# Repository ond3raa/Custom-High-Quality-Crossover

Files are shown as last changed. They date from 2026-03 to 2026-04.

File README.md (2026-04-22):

# Description
This is an audio crossover. Its function is to take an audio signal and split it into multiple speakers based on specific frequencies. It is used in speaker cabinets and sound systems to achieve the correct sound.
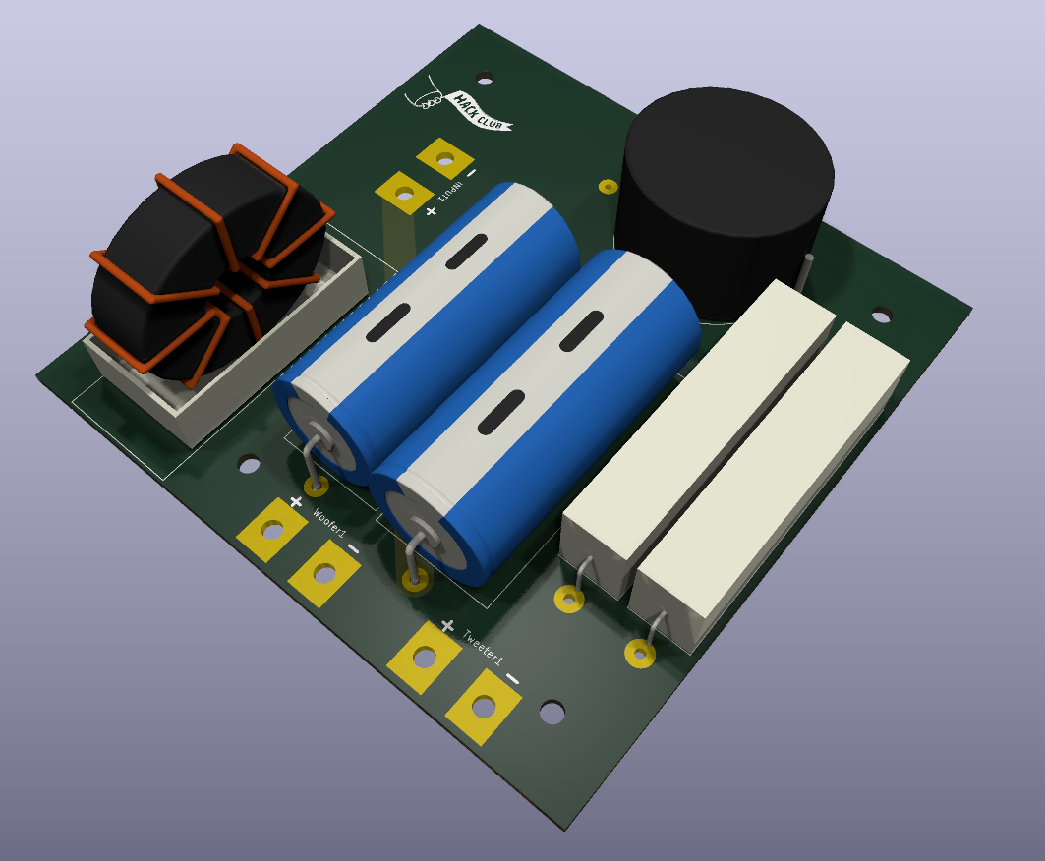
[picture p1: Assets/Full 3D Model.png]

# How to use
The usage is quite simple: just assemble the PCB, solder the cables from the amplifier to the input, and connect the mid-bass speaker to the "woofer" output and the tweeter to the "tweeter" output.

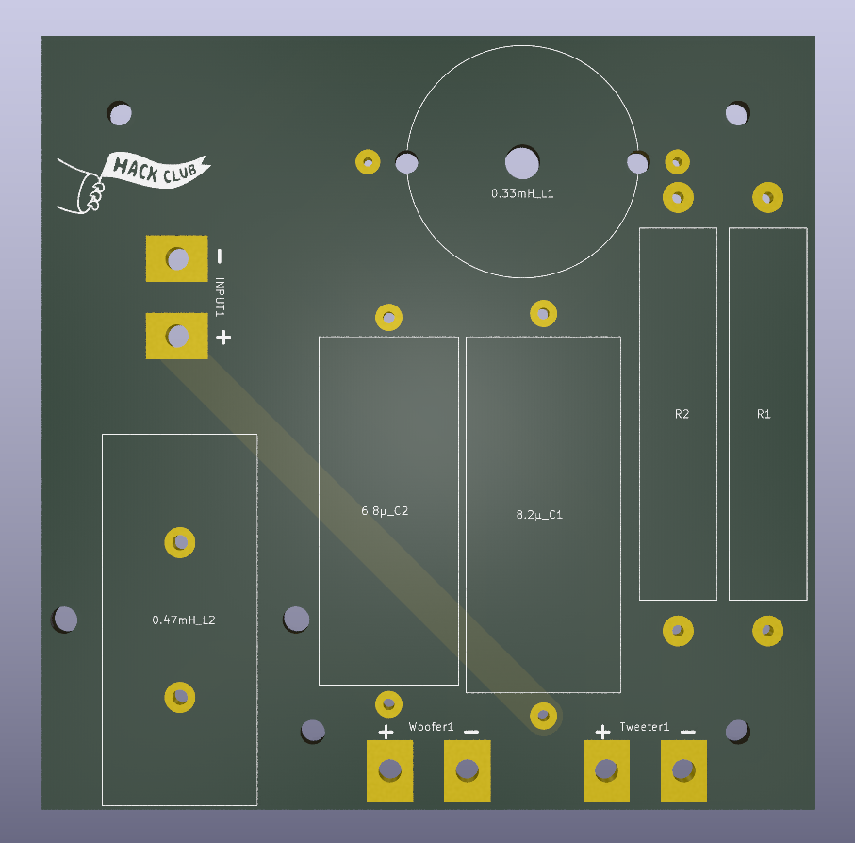
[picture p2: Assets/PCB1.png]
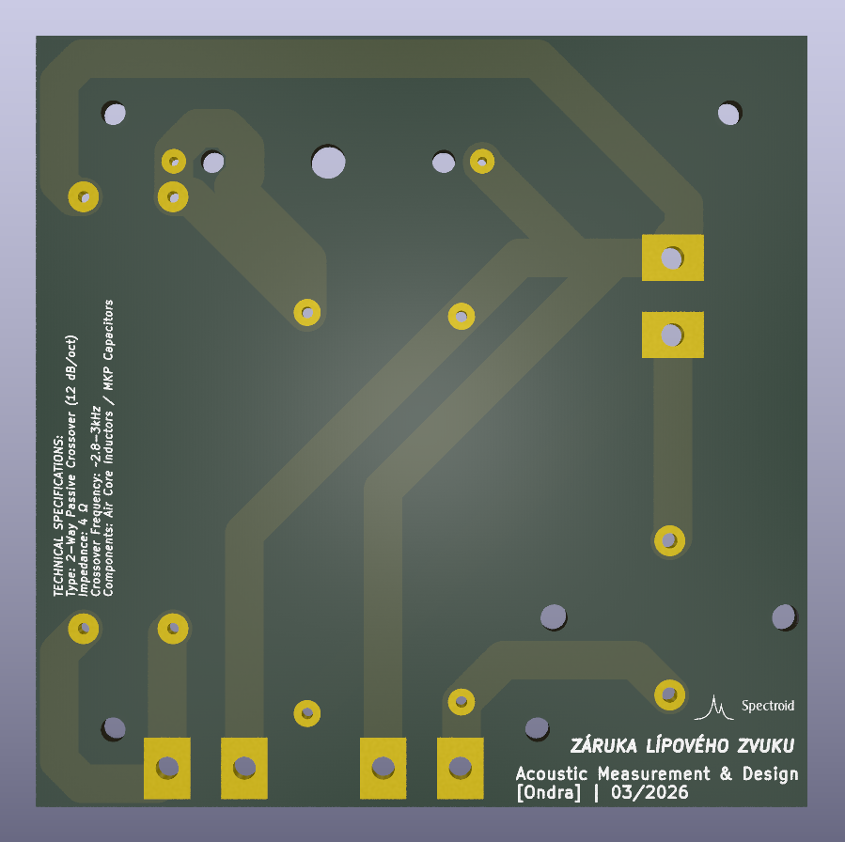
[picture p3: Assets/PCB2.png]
 

# Why I made this
I created this project because I built speaker cabinets using car speakers and wired them the same way they were in the car. At frequencies around 2-10kHz, both speakers played simultaneously due to the missing 2nd-
order crossover, and the sound was sharp and aggressive. I designed this 2nd-order crossover to audibly eliminate this problem and improve the overall sound quality.

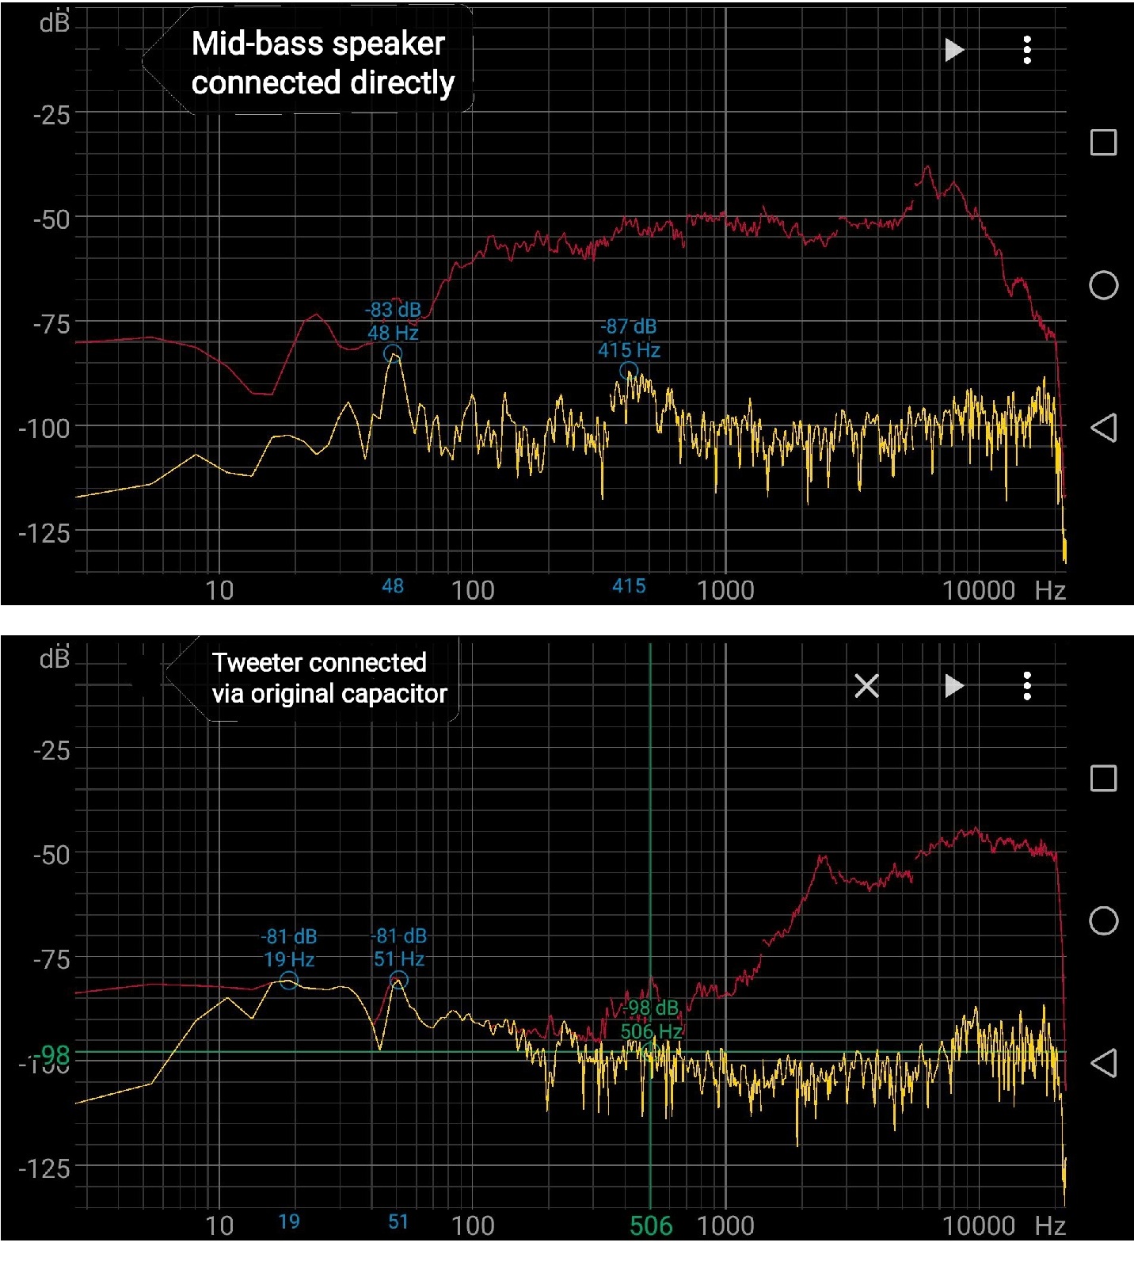
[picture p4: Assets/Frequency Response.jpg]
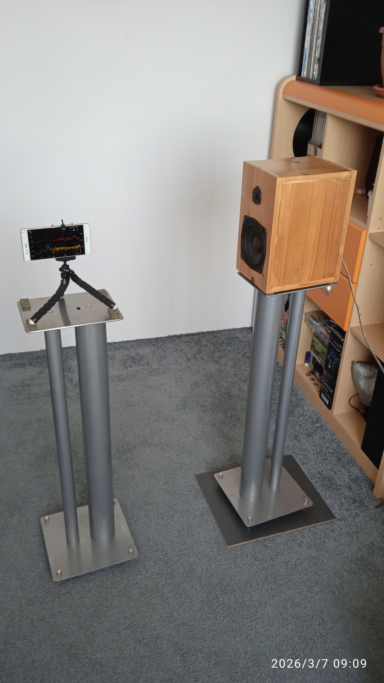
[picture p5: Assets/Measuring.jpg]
 

# Firmware & Software
This project is a passive analog audio crossover. It uses only discrete components, including capacitors, inductors, and resistors for frequency filtering. There are no microcontrollers or integrated circuits involved, so no firmware is required for this project to operate.
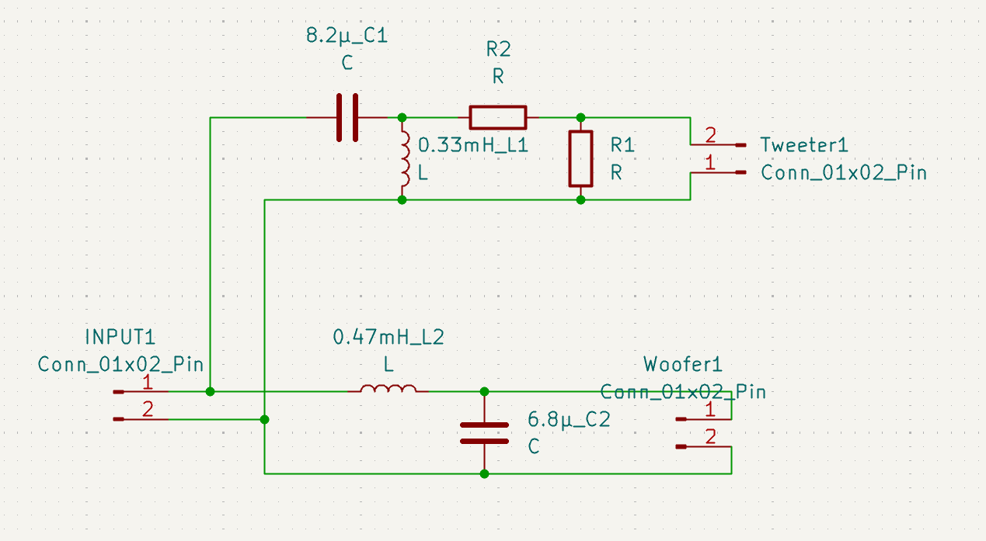
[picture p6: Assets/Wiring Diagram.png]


### BOM

| Part | Value | Quantity | Price (CZK) | Link |
| :--- | :--- | :--- | :--- | :--- |
| Connecting cables | | 6 | 0 - I have them | - |
| Mounting screws | M3 | 8 | 0 - I have them | - |
| Air coil L1 | 0.33mH | 2 | 260 | [Link](https://www.reproobchod.cz/dexon-vzduchova-civka-0-33mh-0-8mm/) |
| Air coil L2 | 0.47mH | 2 | 338 | [Link](https://www.reproobchod.cz/monacor-lsip-47-2-vzduchova-civka-0-47mh-0-85mm/) |
| Capacitor C1 | 8.2uF | 2 | 192 | [Link](https://www.reproobchod.cz/kondenzator-monacor-mkpa-82-8-2uf-250v-dc-mkp/) |
| Capacitor C2 | 6.8uF | 2 | 190 | [Link](https://www.reproobchod.cz/kondenzator-monacor-mkpa-68-6-8uf-250v-dc-mkp/) |
| Resistor R1 | 1 Ohm | 2 | 60 | [Link](https://www.reproobchod.cz/rezistor-keramicky-visaton-r-1ohm-10-w/) |
| Resistor R2 | 1.5 Ohm | 2 | 60 | [Link](https://www.reproobchod.cz/rezistor-keramicky-visaton-r-1-5ohm-10-w/) |
| Resistor R3 | 2.2 Ohm | 2 | 36 | [Link](https://www.reproobchod.cz/rezistor-keramicky-dratovy-tesla-tr271-2r2-10w/) |
| Resistor R4 | 3 Ohm | 2 | 36 | [Link](https://www.reproobchod.cz/rezistor-keramicky-dratovy-tesla-tr271-3r0-10w/) |
| Shipping | reproobchod.cz | 1 | 69 | - |
| PCB | JLCPCB | 2 | ~90 | [Link](https://jlcpcb.com/) |
| **Total to pay** | | | **1331 CZK** | **~$63.97 USD** |

## Note:
## The real value in dollars is here in the BOM. It is also in the blueprint project, but it differs due to different exchange rates
The 3D component models used in the CAD assembly and STEP file are **representative placeholders**.

I selected these models based on their physical dimensions (length and width) to verify component clearance and PCB seating. The actual high-quality audio components (inductors and capacitors) used for assembly are precisely specified in the **Bill of Materials**.

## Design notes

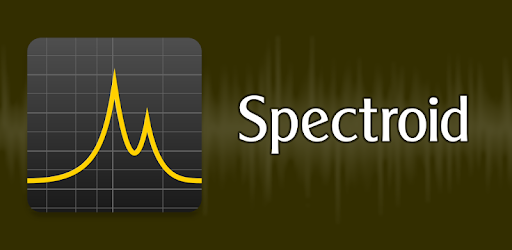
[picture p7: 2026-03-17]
3D model/Used models/org.intoorbit.spectrum-header.png

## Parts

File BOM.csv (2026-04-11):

Designator | Value | Quantity | Link
Connecting cables |  | 6 but i have them
Mounting screws | M3 | 8 but i have them
L1 | 0.33mH | 2 | https://www.reproobchod.cz/dexon-vzduchova-civka-0-33mh-0-8mm/
L2 | 0.47mH | 2 | https://www.reproobchod.cz/monacor-lsip-47-2-vzduchova-civka-0-47mh-0-85mm/
C1 | 8.2uF | 2 | https://www.reproobchod.cz/kondenzator-monacor-mkpa-82-8-2uf-250v-dc-mkp/
C2 | 6.8uF | 2 | https://www.reproobchod.cz/kondenzator-monacor-mkpa-68-6-8uf-250v-dc-mkp/
R1 | 1 Ohm | 2 | https://www.reproobchod.cz/rezistor-keramicky-visaton-r-1ohm-10-w/
R2 | 1.5 Ohm | 2 | https://www.reproobchod.cz/rezistor-keramicky-visaton-r-1-5ohm-10-w/
R3 | 2.2 Ohm | 2 | https://www.reproobchod.cz/rezistor-keramicky-dratovy-tesla-tr271-2r2-10w/
R4 | 3 Ohm | 2 | https://www.reproobchod.cz/rezistor-keramicky-dratovy-tesla-tr271-3r0-10w/
JLCPCB | Custom | 2 | https://jlcpcb.com/

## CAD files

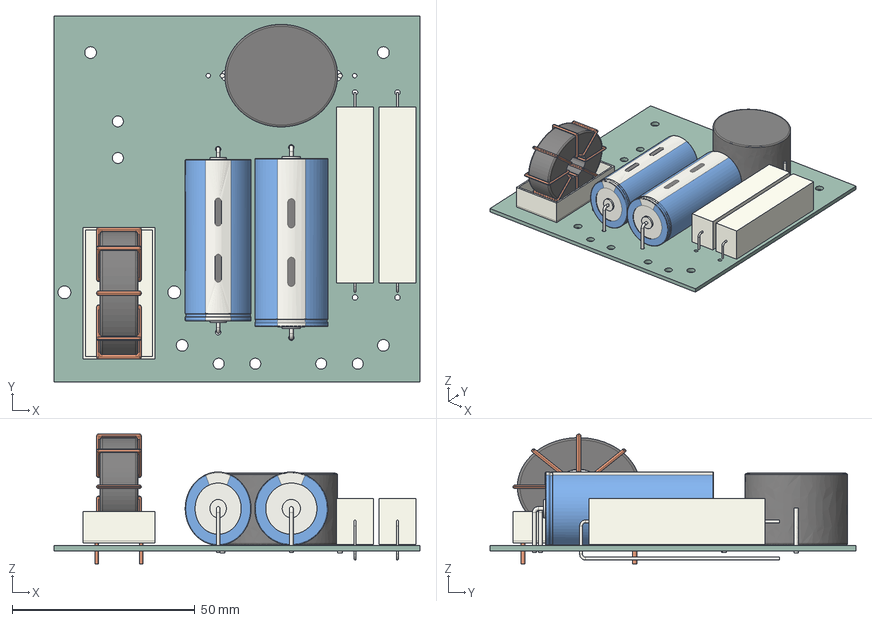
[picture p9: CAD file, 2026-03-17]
3D model/Crossover test.step
100.0 x 100.0 x 35.5 mm
L_Radial_D28.0mm_P29.20mm
R_Axial_Power_L48.0mm_W12.5mm_P10.16mm_Vertical x 2
CP_Axial_L46.0mm_D20.0mm_P52.00mm_Horizontal
L_CommonMode_Toroid_Vertical_L24.0mm_W16.3mm_Px10.16mm_Py20.32mm_ Murata_5200
CP_Axial_L46.0mm_D20.0mm_P52.00mm_Horizontal (1)
Crossover test_PCB

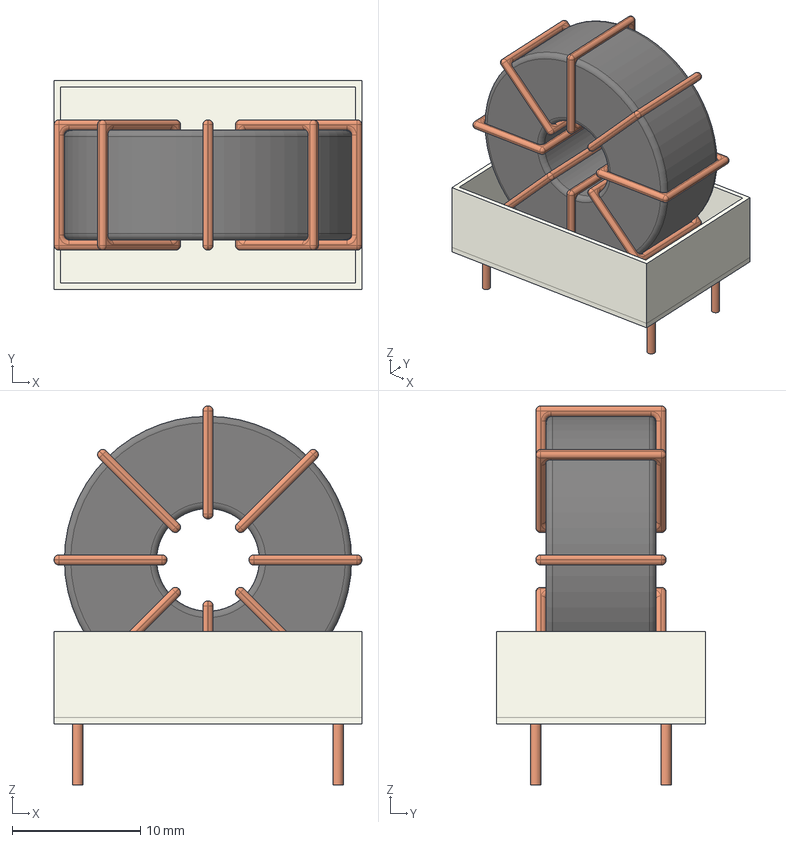
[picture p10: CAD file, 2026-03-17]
3D model/Used models/L_CommonMode_Toroid_Vertical_L24.0mm_W16.3mm_Px10.16mm_Py20.32mm_Murata_5200.step
24.0 x 16.3 x 29.6 mm

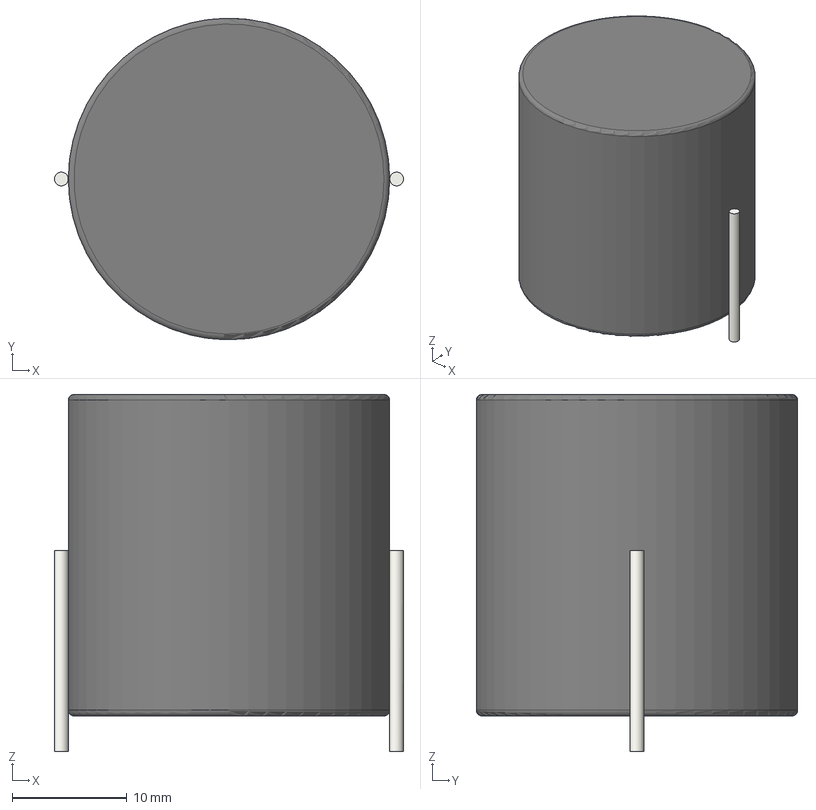
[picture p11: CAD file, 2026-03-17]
3D model/Used models/L_Radial_D28.0mm_P29.20mm.step
30.4 x 28.0 x 31.1 mm

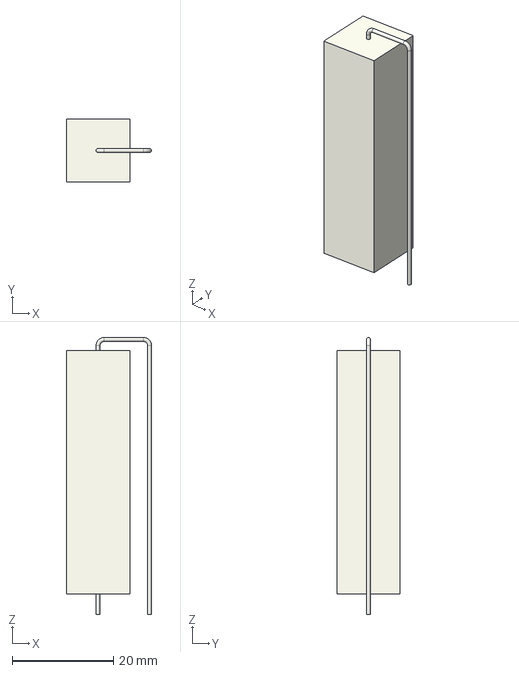
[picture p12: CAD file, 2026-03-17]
3D model/Used models/R_Axial_Power_L48.0mm_W12.5mm_P10.16mm_Vertical.step
16.8 x 12.5 x 54.6 mm

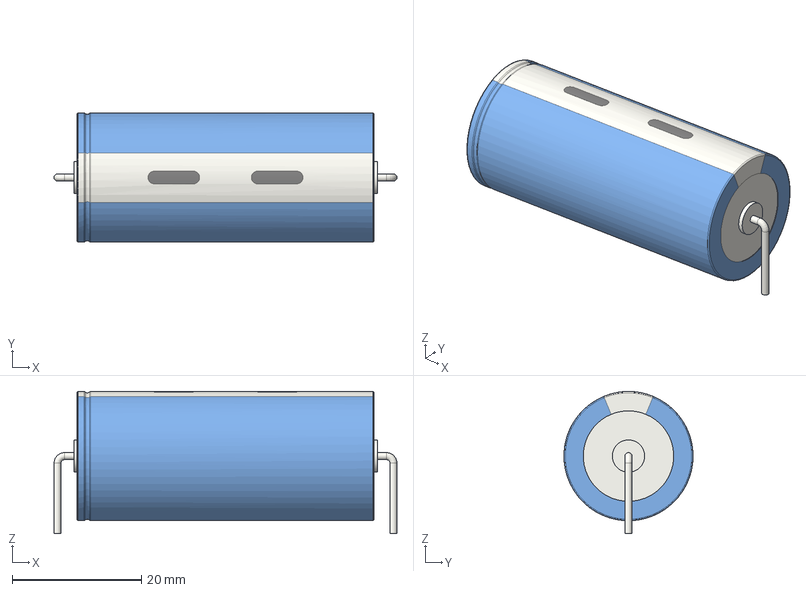
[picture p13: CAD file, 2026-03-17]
3D model/Used models/CP_Axial_L46.0mm_D20.0mm_P52.00mm_Horizontal.step
53.1 x 20.0 x 22.0 mm

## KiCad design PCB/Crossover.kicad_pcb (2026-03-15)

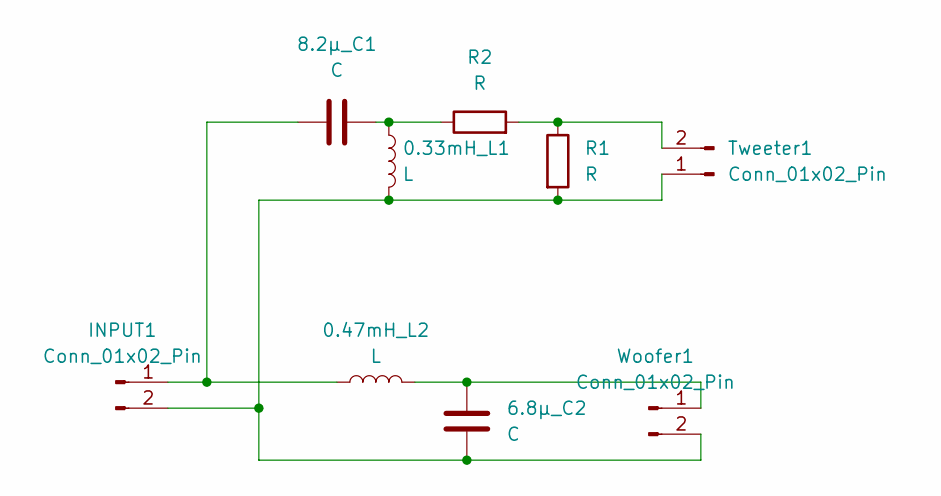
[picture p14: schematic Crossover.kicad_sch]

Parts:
0.33mH_L1: L; DEXON vzduchová cívka 0,8mm
0.47mH_L2: L; MONACOR LSIP-472
6.8µ_C2: C; MONACOR MKPA-68
8.2µ_C1: C; MONACOR MKPA-82
INPUT1: Conn_01x02_Pin; Konektor připojovací
R1, R2: R; Rezistor keramický
Tweeter1: Conn_01x02_Pin; Konektor připojovací
Woofer1: Conn_01x02_Pin; Konektor připojovací

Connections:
unnamed: 0.33mH_L1.1, 8.2µ_C1.2, R2.1
unnamed: 0.47mH_L2.1, 8.2µ_C1.1, INPUT1.1
unnamed: 0.33mH_L1.2, 6.8µ_C2.2, INPUT1.2, R1.2, Tweeter1.1, Woofer1.2
unnamed: R1.1, R2.2, Tweeter1.2
unnamed: 0.47mH_L2.2, 6.8µ_C2.1, Woofer1.1

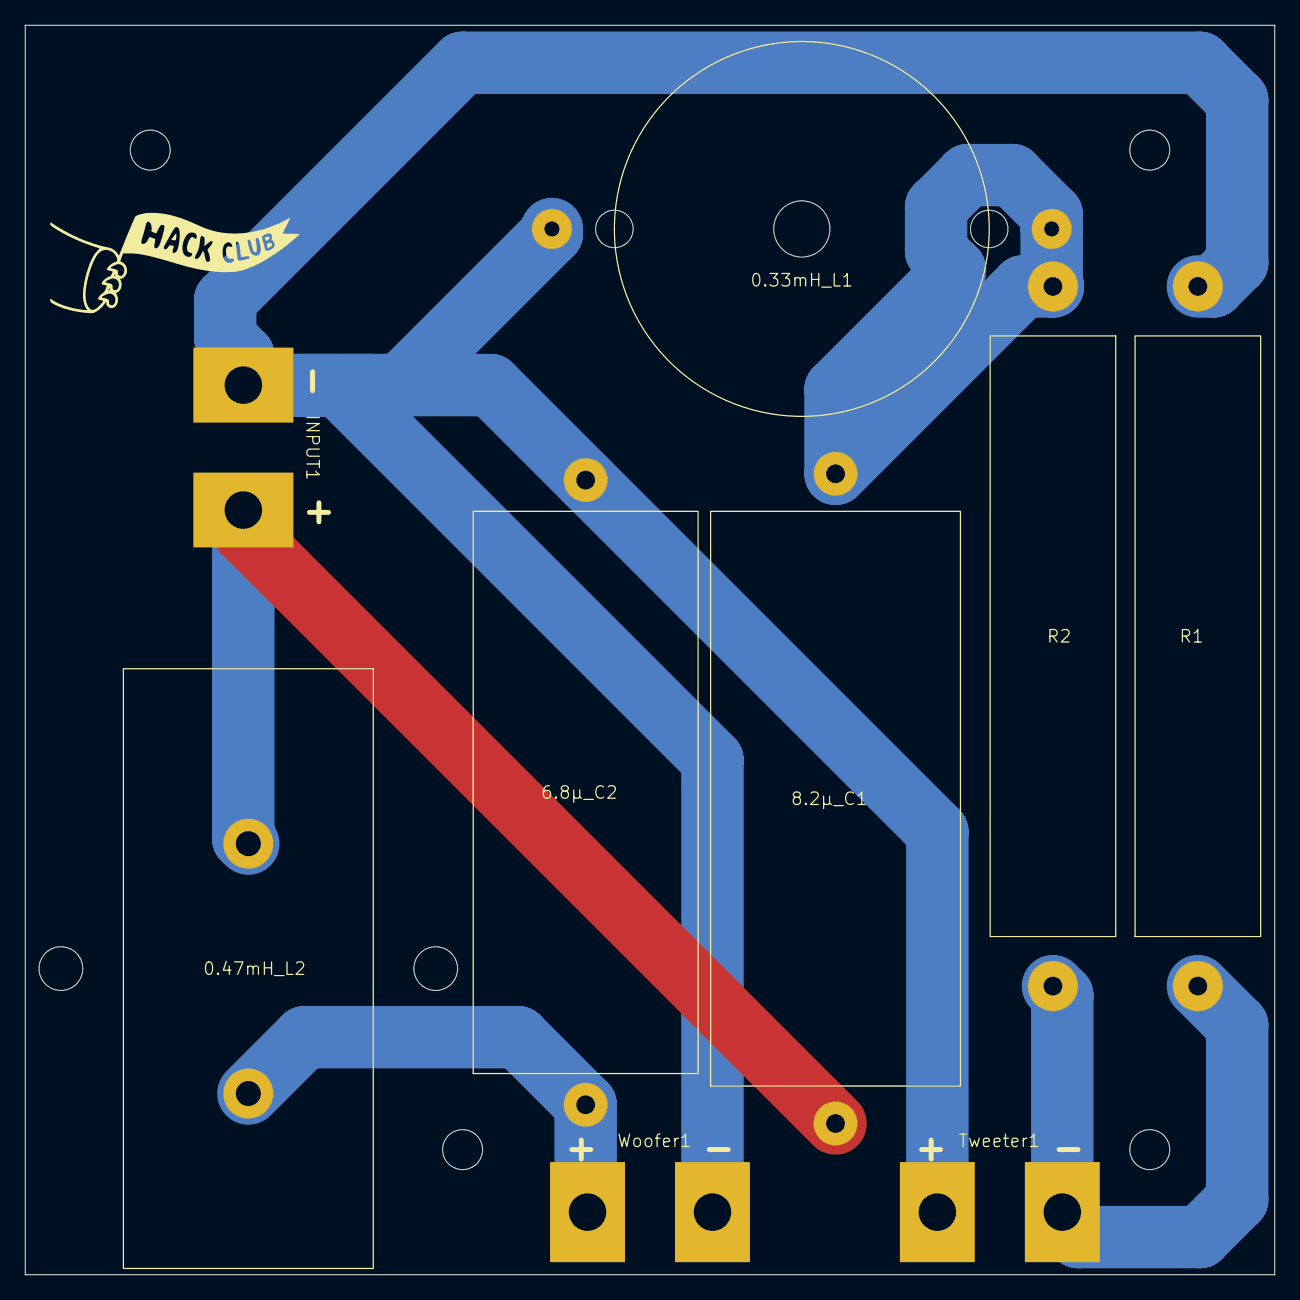
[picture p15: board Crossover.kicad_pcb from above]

Board: 2 copper layers, 100.0 x 100.0 mm, 9 parts (0 on the bottom side), 5 nets.

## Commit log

2026-03-15 Created pcb folder
2026-03-15 Added kicad files
    [Crossover.kicad_pcb, Crossover.kicad_sch]
2026-03-15 Create PCB
2026-03-17 Add BOM.csv
    [BOM.csv]
2026-03-17 Add gerbers zip
2026-03-17 Add step model
    [Crossover test.step]
2026-03-17 Add used models
    [CP_Axial_L46.0mm_D20.0mm_P52.00mm_Horizontal.step, L_CommonMode_Toroid_Vertical_L24.0mm_W16.3mm_Px10.16mm_Py20.32mm_Murata_5200.step, L_Radial_D28.0mm_P29.20mm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]

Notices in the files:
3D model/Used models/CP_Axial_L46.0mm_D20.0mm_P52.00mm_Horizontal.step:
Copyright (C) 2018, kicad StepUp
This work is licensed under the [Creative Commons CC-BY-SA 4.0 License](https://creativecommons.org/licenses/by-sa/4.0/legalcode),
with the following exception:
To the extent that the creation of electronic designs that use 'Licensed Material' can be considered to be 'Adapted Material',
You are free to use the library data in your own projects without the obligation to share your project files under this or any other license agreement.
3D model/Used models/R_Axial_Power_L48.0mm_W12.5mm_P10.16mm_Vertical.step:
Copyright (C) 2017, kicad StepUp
